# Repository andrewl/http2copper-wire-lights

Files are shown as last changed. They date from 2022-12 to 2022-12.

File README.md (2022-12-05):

HTTP Control of copper wire lights
----------------------------------

Control copper wire lights over WiFi with an ESP8266.

What this does
--------------

It allows you to control a string of copper wire
lights over an http API. You can switch them on, off and rotate through a number of patterns 
(constant on, flashing fast, flashing slow, fading slow, fadingslow, off).

And because we're now API driven you can hook it your lights up to Home Assistant,
node-red or a home automation platform of your choice.

https://user-images.githubusercontent.com/114216/205506635-eeabcf92-20b1-415c-ae01-2569513f0ec1.mov

How copper wire lights works
----------------------------

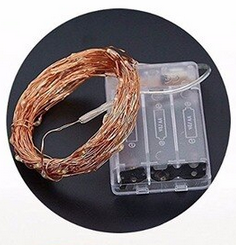
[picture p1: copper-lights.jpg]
Copper wire lights


They're a series of LEDs on a copper wire. The D in LED stands for Diode, and a diode
only lets current flow in one direction. The LEDs in these lights are wired up in
alternating directions so that 50% of them light up when electricty flows one way,
50% of them when it flows in the other direction. 

We can use an L923D circuit to switch the polarity of the voltage that we apply to
the copper lights. These circuits (also known as H or half-H bridges) are 
commonly used to drive motors - applying current in one polarity drives the
motor in one direction, switching the polarity drives the motor in another.

We're just using the polarity switch to turn on one set of LEDs or the other,
and a principle called Pulse Width Modulation (pwm) to set the brightness of the
selected LEDs.

How to build
------------

You'll need
- 1 x Wemos D1 mini (or similar)
- 1 x L923D motor driver switch
- 1 x Breadboard
- 1 x Bunch of jumper wires
- 1 x string of copper lights (the ones that take 3 x AA batteries - 4.5v)

This is a fairly straightforward breadboard build for anyone who has already put
together a few breadboarded circuits with an Arduino, ESP8266 or similar.

1. Build the circuit as per the diagram below. Pay close attention to the connections
between the L923D and Wemos D1 mini.
2. You will have two wires that remain unconnected. These will provide power to
the lights. These are the pink wires in the diagram below.
3. Cut the battery box from lights, fairly close to the battery box so you have
plenty of wire remaining.
4. Strip off some of the wire attached to the lights that was previously attached
to the battery box
5. Connect one of the wires you just stripped to one of the unconnected wires
on the L923D. It doesn't matter which.
6. Connect the remaining wire to the remaining wire on the L923D.
7. Copy the file ./secrets.h.EXAMPLE to secrets.h and edit it so that it contains
your Wifi SSID and password
7. Compile and upload the code contained in http2copper-wire-lights.ino
8. Start up a serial monitor and hit the reset button on the Wemos D1 mini. After
it's connected to your wifi it will report it's IP address. 
9. You can use the IP address to connect to the API using your browser. eg if
the reported IP adress is 192.168.0.100 you can visit http://192.168.0.10/next
to cycle though the light's patterns.

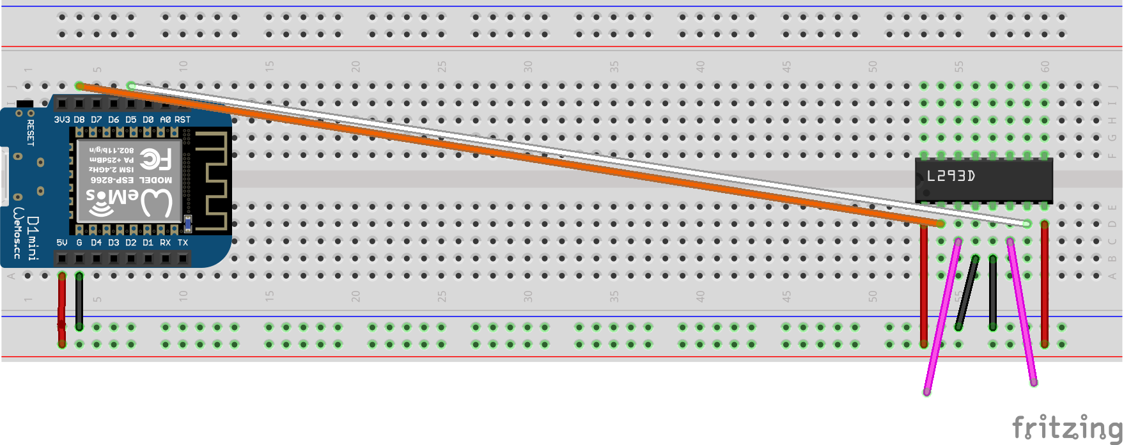
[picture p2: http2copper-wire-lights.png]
Circuit diagram


How to use
----------

After starting up the lights will be in 'constant on' mode. You can then use the API

The API has the following endpoints

```
/next - change the lights to display the next pattern in the sequence
/random - display a random pattern (excluding 'off')
/off - turn the lights off
```

The response will always be a json payload describing the pattern.

License and liability
---------------------

All code, instructions, diagrams released under MIT License.

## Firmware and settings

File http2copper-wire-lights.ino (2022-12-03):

#include "secrets.h"
#include <ESP8266WiFi.h>
#include <ESP8266WebServer.h>

// To speak to the outside world
WiFiClient espClient;

// Create AsyncWebServer object on port 80
ESP8266WebServer server(80);

// Pick any 2 pins that can be commanded with analogWrite (on Wemos D1 mini
// this should be any pins)
int pin1 = D5;
int pin2 = D8;

// pattern - a Struct containing the variables that define a pattern of lights
typedef struct {
  int brightnessDelta; //the change in brightness between steps 0-255
  int stepDelay; //delay between steps in milliseconds
  int initialBrightness; //the initial brightness
} pattern;


// This is where the patterns are defined
pattern patterns[7] = {
  // Off
  {
    .brightnessDelta = 0,
    .stepDelay = 10000000,
    .initialBrightness = 0,
  },
  // Permanently on
  {
    .brightnessDelta = 0,
    .stepDelay = 100,
    .initialBrightness = 255,
  },
  // Flashing, every 1 second
  {
    .brightnessDelta = 255,
    .stepDelay = 1000,
    .initialBrightness = 255,
  },
 // Flashing, every 2.5 second
  {
    .brightnessDelta = 255,
    .stepDelay = 2500,
    .initialBrightness = 255,
  },
  // Fast Increment
  {
    .brightnessDelta = 50,
    .stepDelay = 100,
    .initialBrightness = 255,
  },
  // Slow Increment
  {
    .brightnessDelta = 5,
    .stepDelay = 80,
    .initialBrightness = 255,
  },
};


int patternsCount;

// These all contain application state
int currentPatternIdx;
int nextBrightness;
int brightnessModifier;
int curPin;
int waitUntilMillis = 0;
pattern curPattern;

void setup() {
  Serial.begin(115200);
  pinMode(pin1, OUTPUT);
  pinMode(pin2, OUTPUT);

  brightnessModifier = -1;
  curPin = pin1;

  patternsCount = sizeof(patterns) / sizeof(pattern);
  currentPatternIdx = 1;

  changePattern(currentPatternIdx);

  setup_wifi();
  setup_routes();
}

void loop() {

  // Listen for new commands on the http API
  server.handleClient();

  // if we've not hit the time at which we need to do something else
  // to the lights then just return
  if (waitUntilMillis > millis()) {
    return;
  }

  // We're at the time that we need to execute the next step on the 
  // display of the lights

  // First, write the current brightness to the current pin
  analogWrite(curPin, nextBrightness);

  // If we've hit the minimum brightness then switch polarity
  // by switching the current pin
  if (nextBrightness == 0) {
    if (curPin == pin1) {
      curPin = pin2;
    }
    else {
      curPin = pin1;
    }
  }

  // Change the brightness to set next time around by applying the modifier
  // (which determined whether we're getting brighter or dimmer) to the 
  // brightness delta (which determines how fast the lights get brighter or 
  // dimmer.
  nextBrightness += (brightnessModifier * patterns[currentPatternIdx].brightnessDelta);

  // If the brightness is now 255 or more, pin the brightness to 255 (the max)
  // then next time start getting dimmer
  if (nextBrightness > 254) {
    nextBrightness = 255;
    brightnessModifier = -1;
  }

  // If the brightness is now 0 or less, pin the brightness to 0 then next time
  // start getting brighter
  if (nextBrightness < 1) {
    nextBrightness = 0;
    brightnessModifier = 1;
  }

  // Determine when we need to set the brightness of the lights again
  waitUntilMillis = millis() + patterns[currentPatternIdx].stepDelay;

}

void setup_wifi() {

  delay(10);

  // We start by connecting to a WiFi network
  Serial.println();
  Serial.print("Connecting to WiFi ");
  Serial.println(ssid);

  WiFi.mode(WIFI_STA);
  WiFi.begin(ssid, password);

  while (WiFi.status() != WL_CONNECTED) {
    delay(500);
    Serial.print(".");
  }

  Serial.println("");
  Serial.println("WiFi connected");
  Serial.println("IP address: ");
  Serial.println(WiFi.localIP());
}

void setup_routes() {

  // Start Web Server
  server.on("/", getCurrentPattern);
  server.on("/next", nextPattern);
  server.on("/random", randomPattern);
  server.on("/off", offPattern);

  server.onNotFound(notFoundPage);
  server.begin();
}

// Switch to the next pattern
void nextPattern() {
  currentPatternIdx++;
  if (currentPatternIdx >= patternsCount) {
    currentPatternIdx = 0;
  }
  changePattern(currentPatternIdx);
  server.send(200, "text/json", curPatternToJSONString());
}

// Returns the current pattern
void getCurrentPattern() {
  server.send(200, "text/json", curPatternToJSONString());
}

// Changes to the "off" pattern (pattern 0)
void offPattern() {
  changePattern(0);
  server.send(200, "text/json", curPatternToJSONString());
}

// Selects a random pattern
void randomPattern() {
  int randomPatternIndex = random(1,patternsCount-1);
  changePattern(randomPatternIndex);
  server.send(200, "text/json", curPatternToJSONString());
}

// Not found page
void notFoundPage() {
  server.send(404, "text/plain", "Not found");
}

// Change the current pattern to the one specified. If the specified
// pattern is out of range, select pattern 0.
void changePattern(int newPatternIdx) {
  if (newPatternIdx > patternsCount || newPatternIdx < 0) {
    newPatternIdx = 0;
  }
  curPattern = patterns[newPatternIdx];
  currentPatternIdx = newPatternIdx;
  nextBrightness = curPattern.initialBrightness;
  waitUntilMillis = 0;
}

//formats a pattern as a json String
String curPatternToJSONString() {
  String initialBrightness = "\"initialBrightness\" : " + String(curPattern.initialBrightness);
  String brightnessDelta = "\"brightnessDelta\" : " + String(curPattern.brightnessDelta);
  String stepDelay = "\"stepDelay\" : " + String(curPattern.stepDelay);
  return "{\n  " + initialBrightness + ",\n  " + brightnessDelta + ",\n  " + stepDelay + "\n}";
}
